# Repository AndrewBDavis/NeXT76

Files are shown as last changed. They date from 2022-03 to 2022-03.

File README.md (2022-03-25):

NeXT76 Left-Handed Alps Keyboard
=====================
The primary goal of this project was create as PCB and accompanying layered acrylic case to exclusively support NeXT non-adb keycaps and Alps Electric SKCM/SKCL switches.

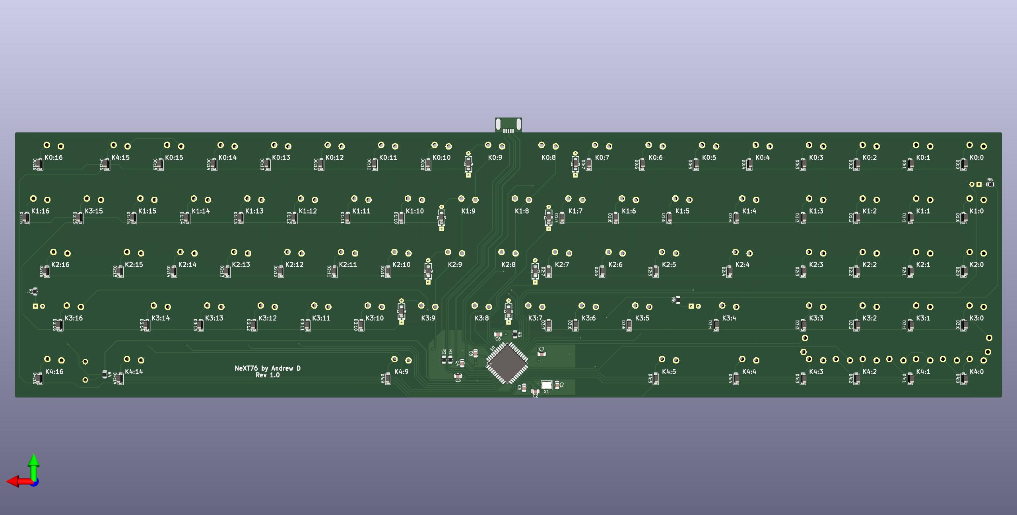
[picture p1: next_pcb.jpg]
next_pcb

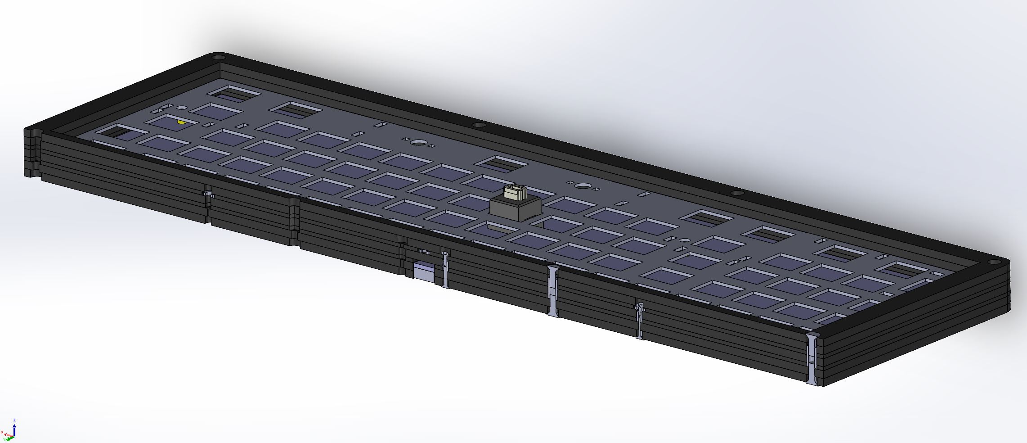
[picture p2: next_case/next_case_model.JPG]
next_model


Supported Layouts
---------------
This keyboard only supports a [modifed NeXT non-adb layout](https://tinyurl.com/mrxz3pk3) with no volume, brightness or arrow keys and a numpad that is moved to the left of the alphanumericals. Shift key leds are supported.

Numpad Layouts supported:  
| 1u | 1u | 1u | 1u |  | 1u | 1u | 1u | 1u |  | 1u | 1u | 1u | 1u |
|----|----|----|----|--|----|----|----|----|--|----|----|----|----|
| 1u | 1u | 1u | 1u |  | 1u | 1u | 1u | 1u |  | 1u | 1u | 1u | 1u |
| 1u | 1u | 1u | 1u |  | 1u | 1u | 1u | 1u |  | 1u | 1u | 1u | 1u |
| 1u | 1u | 1u | 2u |  | 2u | 1u | 1u | 1u |  | 1u | 1u | 1u | 1u |
| 2u | 2u | 1u | 2u |  | 2u | 1u | 2u | 2u |  | 1u | 2u | 2u | 1u |  

(Some layouts not shown explicitly)

BOM for Alps76 keyboard                                                  
------------------
| REF:  | VALUE: | FOOTPRINT: | COMPONENT |
|--- | --- | --- | --- |
| C1 | 22p | C_0805 | |
| C2 | 22p | C_0805 | | 
| C3 | 1u | C_0805 | |
| C4 | 4.7u | C_0805 | |
| C5 | 0.1u | C_0805 | |
| C6 | 0.1u | C_0805 | |
| C7 | 0.1u | C_0805 | |
| C8 | 0.1u | C_0805 | |
| J1 | USB_mini_B | USB_miniB_hirose_5S8 | UX60SC-MB-5S8 Hirose |
| R1 | 22 | R_0805 | |
| R2 | 22 | R_0805 | |
| R3 | 10K | R_0805 | |
| R4 | 10K | R_0805 | |
| R5 | 1K | R_0805 | |
| R6 | 1K | R_0805 | |
| R7 | 1K | R_0805 | |
| SW1 | SW_PUSH | Custom | TE 1825966-1 |
| U1 | ATMEGA32U4 | QFP44 | ATMega32u4-AU | 
| X1 | CRYSTAL | FA-238 | 16MHz, 12PF |
| D(78) | DIODE | SOD-123 | 1N4148 |
| LED(3)| LED | LED_D3.0mm | 3mm Round Top LED |

Revisions
-------------
V0.0: 	Prototype  
V1.0: 	Initial Release  
&emsp;&emsp;&nbsp;&nbsp;Cleaned up trace routing  
&emsp;&emsp;&nbsp;&nbsp;Added more numpad configurations  
V1.1: 	Added second numpad LED location option  
V1.2: 	Updated diode footprints,

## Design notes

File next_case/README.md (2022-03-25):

NeXT76 Acrylic Keyboard Case 
=====================
Layered acrylic layered case consisting of:
---------------
2 layers of 3mm acrylic  (Matte Top Layer Reccomended)  
1 layer of 1.5mm acrylic (1.2mm FR4 plate sits in-line with this layer)   
1 layer of 3mm acrylic (1.2mm FR4 plate sits on top of this layer)  
1 layer of 1.5mm acrylic 
2 layers of 3mm acrylic (Matte Bottom Layer Reccomended)  

Requried Hardware:
---------------
| Description | Thread | Length | Qty: | Locations: | Part number or Standard : |
|---|---|---|---|---|---|
| Hex Standoff Spacers | M3 | 8mm | 8 | Main Mouting Points | M1255-3005-AL |
| Round Standoff Spacers (Brass) | M2 | 4mm | 7 | USB, Plate Mounting | Generic, D3mm |
| Countersunk Hex Socket Screws  | M3 | 8mm | 16 | Main Mouting Points | ISO 10642 / DIN 7991 |
| Countersunk Hex Socket Screws  | M2 | 8mm | 7 | USB, Plate Mounting Points (Bottom) | ISO 10642 / DIN 7991 |
| Button Head Hex Socket Screws  | M2 | 4mm | 7 | USB, Plate Mounting Points (Top) | ISO 7380 / DIN 9427 |

Optional Hardware:
---------------
| Description | Qty: | Notes: |
|---|---|---|
| 22mm Anodized Aluminum Cone Feet | 3 is recommended | Available from Drop, KBDFans, Aliexpress etc. |

**Please note:** To use the aluminum feet, you must use the inclueded countersunk M4 screws and clip the legs of the switches mounted directly above screws and ensure the two are not making contact.

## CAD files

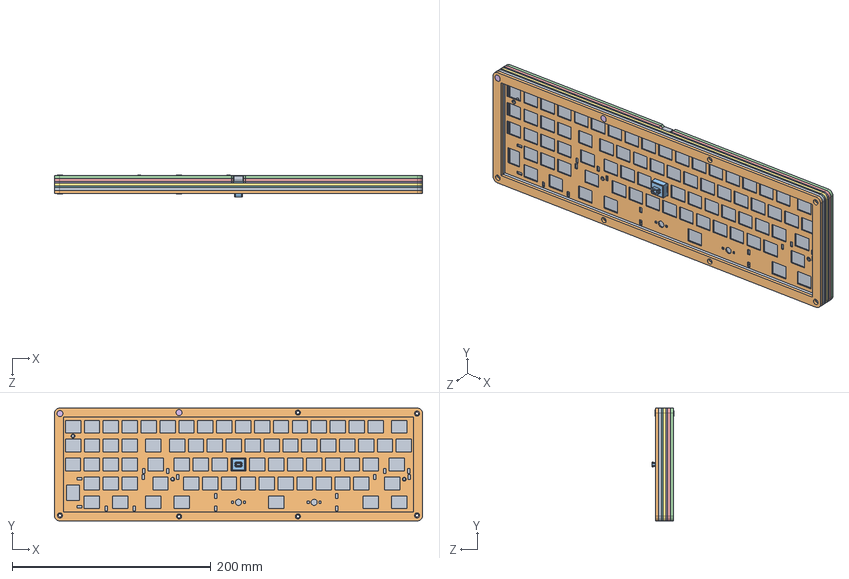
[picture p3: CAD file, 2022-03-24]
next_case/next_case_model/next_assembly.SLDASM
370.8 x 113.6 x 21.9 mm
pcb_next
plate
alps_switch
3mm_matte_1
3mm_2
1_5mm_3
3mm_4
1_5mm_5
3mm_6
3mm_matte_7
hex_spacer x 2
m2_countersunk x 2
m2_button x 2
m3_countersunk x 4

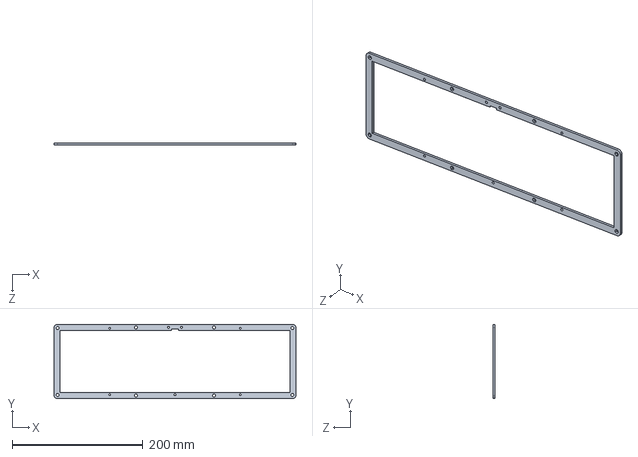
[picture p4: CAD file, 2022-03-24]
next_case/next_case_model/3mm_4.SLDPRT
370.8 x 113.6 x 3.00 mm

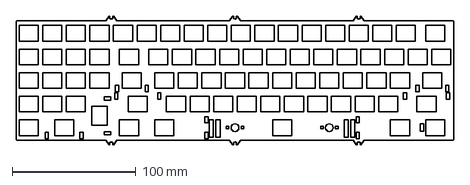
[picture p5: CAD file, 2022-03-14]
next_plate/next_plate.dxf
353.8 x 104.2 mm

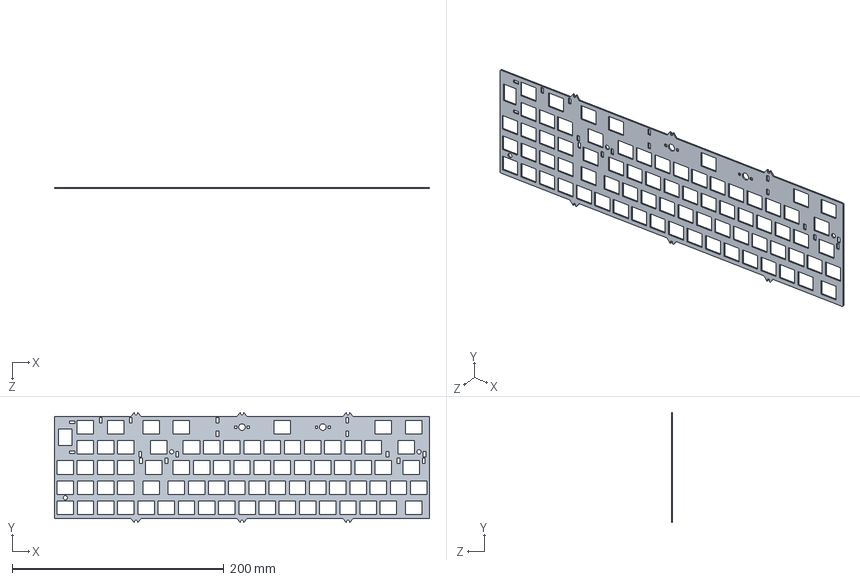
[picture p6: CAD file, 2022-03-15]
next_case/next_case_model/plate.SLDPRT
353.8 x 104.1 x 1.20 mm

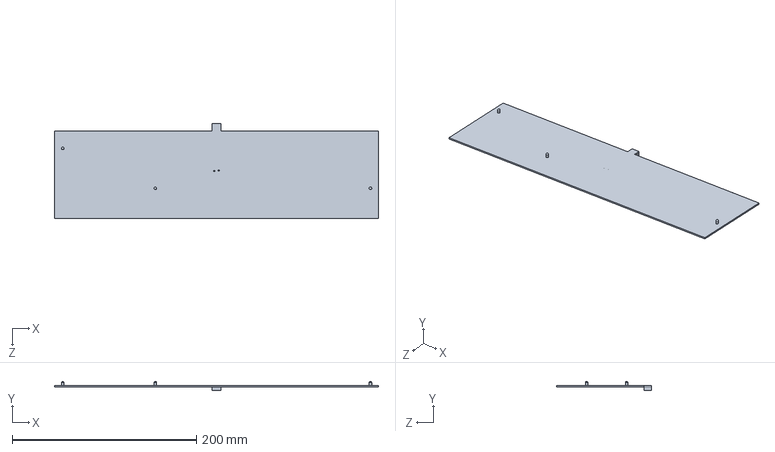
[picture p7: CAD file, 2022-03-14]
next_case/next_case_model/pcb_next.SLDPRT
351.4 x 10.1 x 103.2 mm

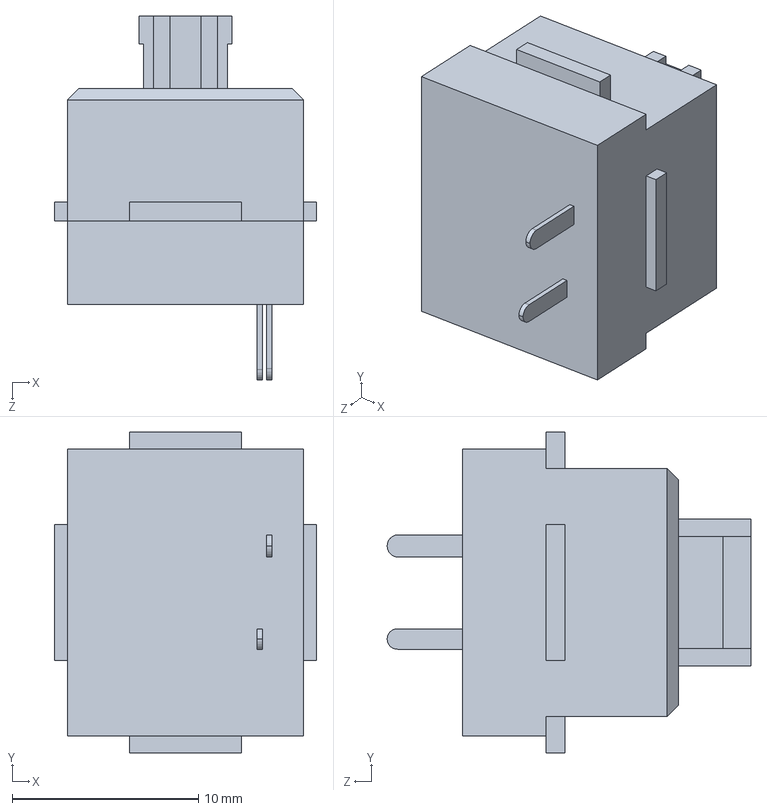
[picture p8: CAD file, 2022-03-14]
next_case/next_case_model/alps_switch.SLDPRT
14.1 x 17.2 x 19.6 mm

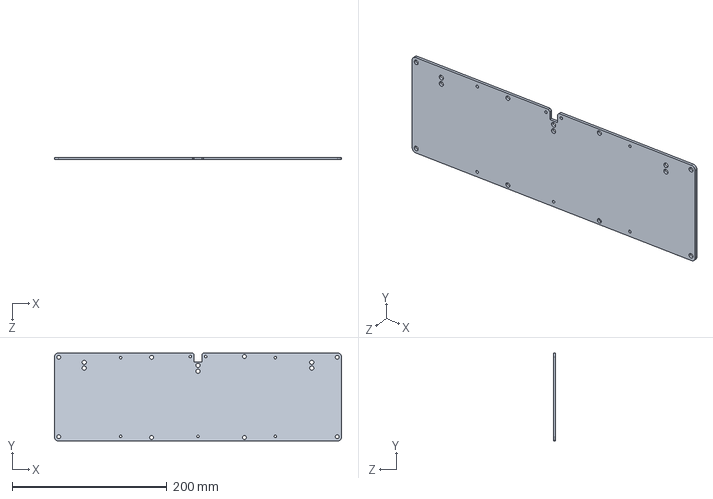
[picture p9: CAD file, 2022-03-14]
next_case/next_case_model/3mm_matte_1.SLDPRT
370.8 x 113.6 x 3.00 mm

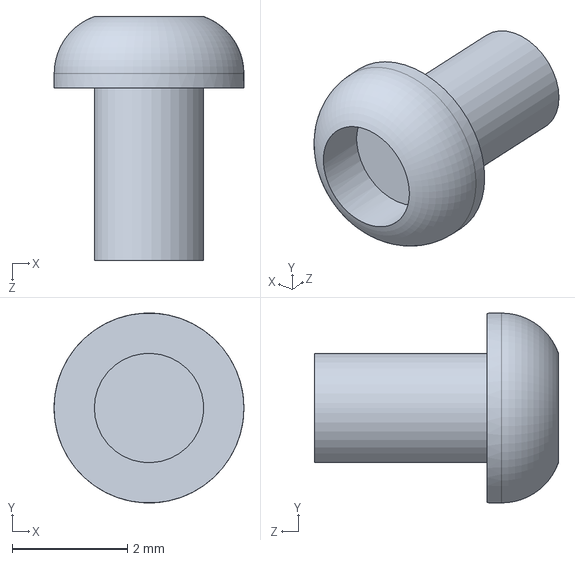
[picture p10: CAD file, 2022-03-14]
next_case/next_case_model/m2_button.SLDPRT
3.30 x 3.30 x 4.24 mm

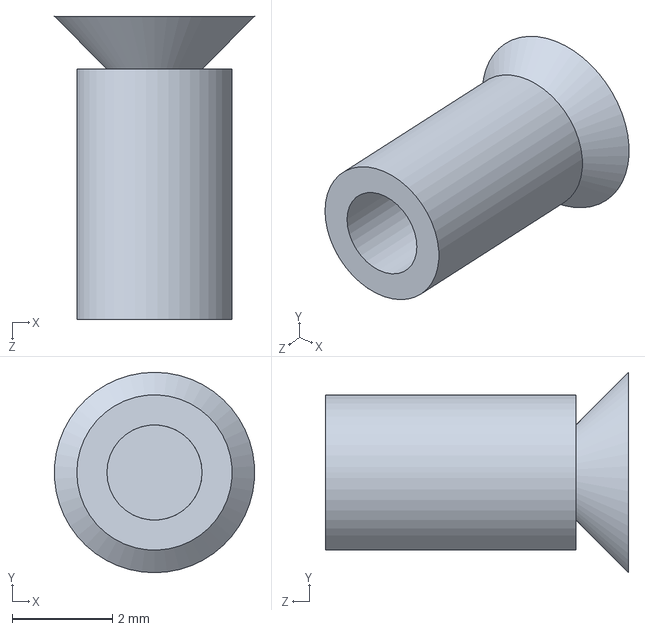
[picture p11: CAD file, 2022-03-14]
next_case/next_case_model/m2_countersunk.SLDPRT
3.99 x 4.00 x 6.05 mm

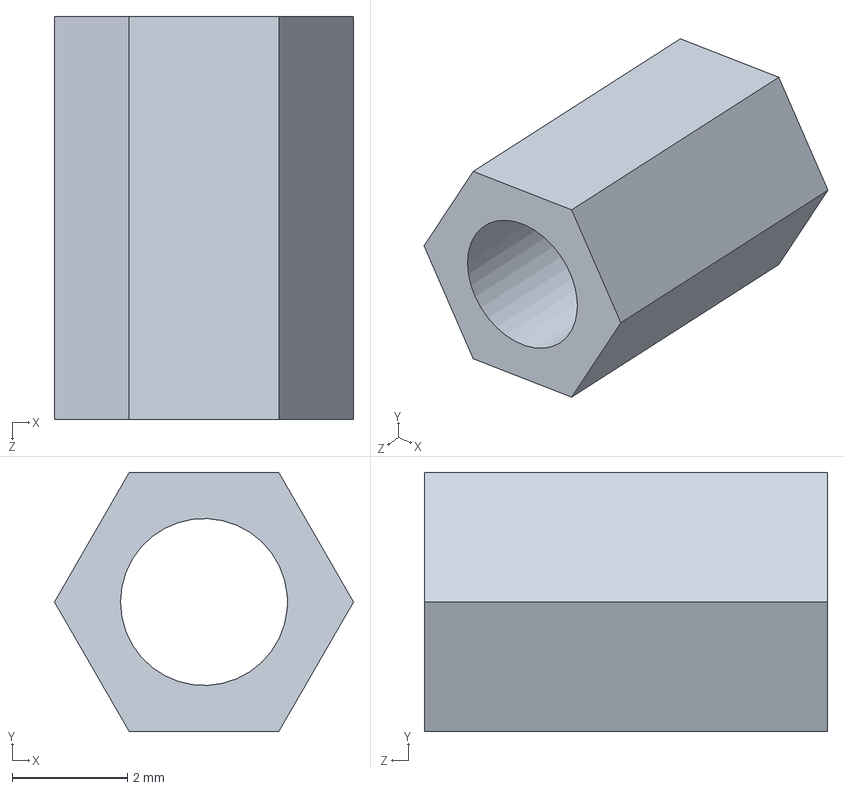
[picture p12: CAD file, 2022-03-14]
next_case/next_case_model/hex_spacer.SLDPRT
5.20 x 4.50 x 7.00 mm

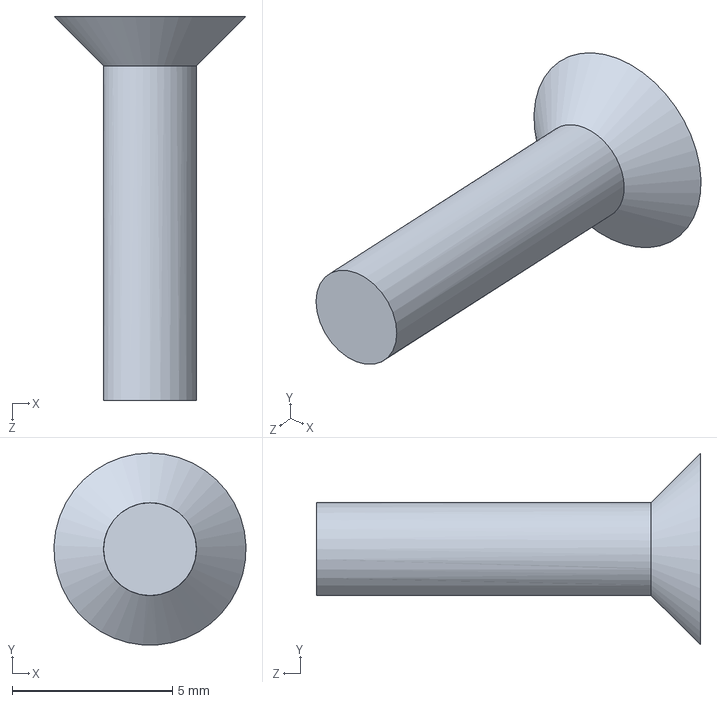
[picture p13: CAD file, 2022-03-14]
next_case/next_case_model/m3_countersunk.SLDPRT
6.00 x 5.99 x 12.0 mm

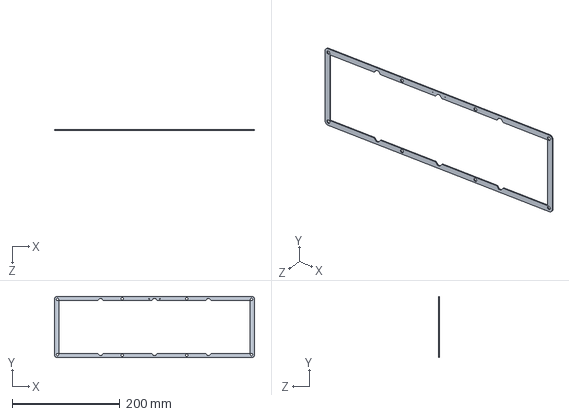
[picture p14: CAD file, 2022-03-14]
next_case/next_case_model/1_5mm_5.SLDPRT
370.8 x 113.6 x 1.50 mm

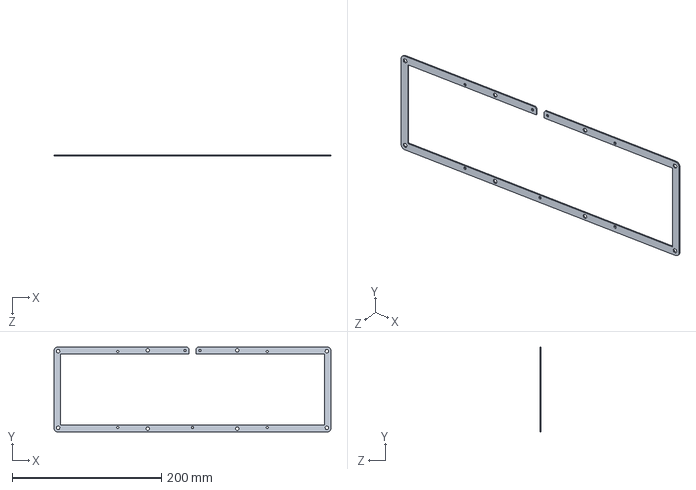
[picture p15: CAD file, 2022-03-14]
next_case/next_case_model/1_5mm_3.SLDPRT
370.8 x 113.6 x 1.50 mm

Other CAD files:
next_case/black_3_mm.dwg
next_case/matte_black_3_mm.dwg
next_case/black_1_5_mm.dwg
next_case/next_case_model/3mm_matte_7.SLDPRT
next_case/next_case_model/3mm_2.SLDPRT
next_case/next_case_model/3mm_6.SLDPRT
next_case/next_case_model/m2_washer.SLDPRT

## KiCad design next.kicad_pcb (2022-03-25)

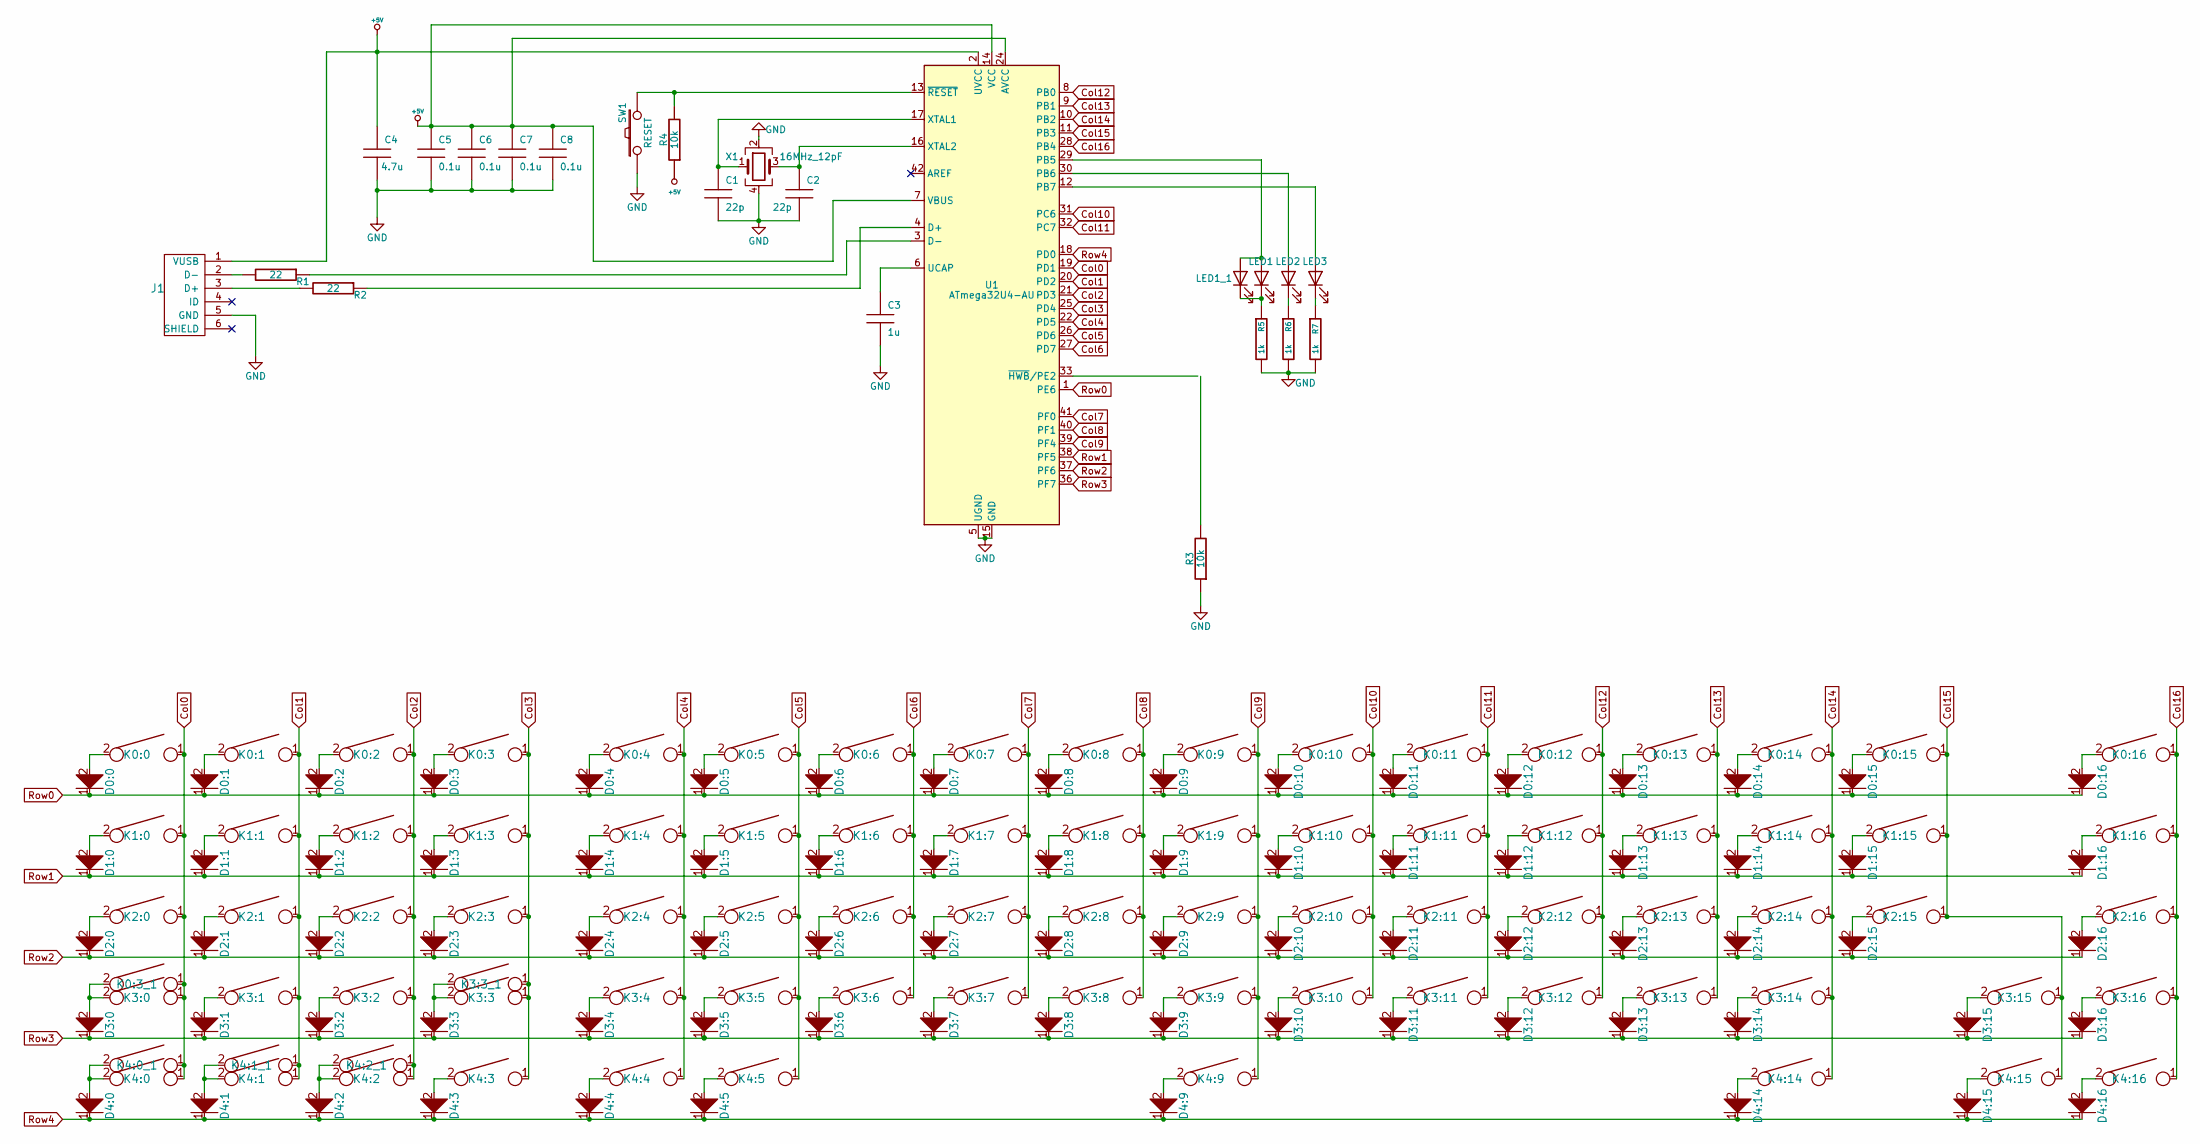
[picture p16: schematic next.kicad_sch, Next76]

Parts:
C1, C2: 22p; C_0805_2012Metric
C3: 1u; C_0805_2012Metric
C4: 4.7u; C_0805_2012Metric
C5, C6, C7, C8: 0.1u; C_0805_2012Metric
D0:0, D0:1, D0:2, D0:3, D0:4, D0:5, D0:6, D0:7, D0:8, D0:9, D0:10, D0:11, D0:12, D0:13, D0:14, D0:15, D0:16, D1:0, D1:1, D1:2, D1:3, D1:4, D1:5, D1:6, D1:7, D1:8, D1:9, D1:10, D1:11, D1:12, D1:13, D1:14, D1:15, D1:16, D2:0, D2:1, D2:2, D2:3, D2:4, D2:5, D2:6, D2:7, D2:8, D2:9, D2:10, D2:11, D2:12, D2:13, D2:14, D2:15, D2:16, D3:0, D3:1, D3:2, D3:3, D3:4, D3:5, D3:6, D3:7, D3:8, D3:9, D3:10, D3:11, D3:12, D3:13, D3:14, D3:15, D3:16, D4:0, D4:1, D4:2, D4:3, D4:4, D4:5, D4:9, D4:14, D4:15, D4:16: D; D_SOD-123
J1: USB_mini_micro_B; USB_miniB_hirose_5S8
K0:0, K0:1, K0:2, K0:3, K0:4, K0:5, K0:6, K0:7, K0:8, K0:9, K0:10, K0:11, K0:12, K0:13, K0:14, K0:15, K0:16, K1:0, K1:1, K1:2, K1:3, K1:4, K1:5, K1:6, K1:7, K1:8, K1:9, K1:10, K1:11, K1:12, K1:13, K1:14, K1:15, K1:16, K2:0, K2:1, K2:2, K2:3, K2:4, K2:5, K2:6, K2:7, K2:8, K2:9, K2:10, K2:11, K2:12, K2:13, K2:14, K2:15, K2:16, K3:0, K3:1, K3:2, K3:3, K3:4, K3:5, K3:6, K3:7, K3:8, K3:9, K3:10, K3:11, K3:12, K3:13, K3:14, K3:15, K3:16, K4:0, K4:1, K4:2, K4:3, K4:4, K4:5, K4:9, K4:14, K4:15, K4:16: KEYSW; Alps
K0:3_1, K3:3_1, K4:0_1, K4:1_1, K4:2_1: KEYSW; Alps_Secondary
LED1, LED1_1, LED2, LED3: LED; LED_D3.0mm
R1, R2: 22; R_0805_2012Metric
R3, R4: 10k; R_0805_2012Metric
R5, R6, R7: 1k; R_0805_2012Metric
SW1: RESET; TE_1825966-1
U1: ATmega32U4-AU; LQFP-44_10x10mm_P0.8mm
X1: 16MHz_12pF; Crystal_SMD_SeikoEpson_FA238-4Pin_3.2x2.5mm

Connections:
+5V: C4.1, C5.1, C6.1, C7.1, C8.1, J1.1 (VUSB), R4.1, U1.2 (UVCC), U1.7 (VBUS), U1.14 (VCC), U1.24 (AVCC), U1.34 (VCC), U1.44 (AVCC)
Col0: K0:0.1, K0:3_1.1, K1:0.1, K2:0.1, K3:0.1, K4:0.1, K4:0_1.1, U1.19 (PD1)
Col1: K0:1.1, K1:1.1, K2:1.1, K3:1.1, K4:1.1, K4:1_1.1, U1.20 (PD2)
Col2: K0:2.1, K1:2.1, K2:2.1, K3:2.1, K4:2.1, K4:2_1.1, U1.21 (PD3)
Col3: K0:3.1, K1:3.1, K2:3.1, K3:3.1, K3:3_1.1, K4:3.1, U1.25 (PD4)
Col4: K0:4.1, K1:4.1, K2:4.1, K3:4.1, K4:4.1, U1.22 (PD5)
Col5: K0:5.1, K1:5.1, K2:5.1, K3:5.1, K4:5.1, U1.26 (PD6)
Col6: K0:6.1, K1:6.1, K2:6.1, K3:6.1, U1.27 (PD7)
Col7: K0:7.1, K1:7.1, K2:7.1, K3:7.1, U1.41 (PF0)
Col8: K0:8.1, K1:8.1, K2:8.1, K3:8.1, U1.40 (PF1)
Col9: K0:9.1, K1:9.1, K2:9.1, K3:9.1, K4:9.1, U1.39 (PF4)
Col10: K0:10.1, K1:10.1, K2:10.1, K3:10.1, U1.31 (PC6)
Col11: K0:11.1, K1:11.1, K2:11.1, K3:11.1, U1.32 (PC7)
Col12: K0:12.1, K1:12.1, K2:12.1, K3:12.1, U1.8 (PB0)
Col13: K0:13.1, K1:13.1, K2:13.1, K3:13.1, U1.9 (PB1)
Col14: K0:14.1, K1:14.1, K2:14.1, K3:14.1, K4:14.1, U1.10 (PB2)
Col15: K0:15.1, K1:15.1, K2:15.1, K3:15.1, K4:15.1, U1.11 (PB3)
Col16: K0:16.1, K1:16.1, K2:16.1, K3:16.1, K4:16.1, U1.28 (PB4)
GND: C1.2, C2.2, C3.2, C4.2, C5.2, C6.2, C7.2, C8.2, J1.5 (GND), R3.1, R5.2, R6.2, R7.2, SW1.1, U1.5 (UGND), U1.15 (GND), U1.23 (GND), U1.35 (GND), U1.43 (GND), X1.2, X1.4
unnamed: C1.1, U1.17 (XTAL1), X1.1
unnamed: C2.1, U1.16 (XTAL2), X1.3
unnamed: C3.1, U1.6 (UCAP)
unnamed: D0:0.2, K0:0.2
unnamed: D0:1.2, K0:1.2
unnamed: D0:2.2, K0:2.2
unnamed: D0:3.2, K0:3.2
unnamed: D0:4.2, K0:4.2
unnamed: D0:5.2, K0:5.2
unnamed: D0:6.2, K0:6.2
unnamed: D0:7.2, K0:7.2
unnamed: D0:8.2, K0:8.2
unnamed: D0:9.2, K0:9.2
unnamed: D0:10.2, K0:10.2
unnamed: D0:11.2, K0:11.2
unnamed: D0:12.2, K0:12.2
unnamed: D0:13.2, K0:13.2
unnamed: D0:14.2, K0:14.2
unnamed: D0:15.2, K0:15.2
unnamed: D0:16.2, K0:16.2
unnamed: D1:0.2, K1:0.2
unnamed: D1:1.2, K1:1.2
unnamed: D1:2.2, K1:2.2
unnamed: D1:3.2, K1:3.2
unnamed: D1:4.2, K1:4.2
unnamed: D1:5.2, K1:5.2
unnamed: D1:6.2, K1:6.2
unnamed: D1:7.2, K1:7.2
unnamed: D1:8.2, K1:8.2
unnamed: D1:9.2, K1:9.2
unnamed: D1:10.2, K1:10.2
unnamed: D1:11.2, K1:11.2
unnamed: D1:12.2, K1:12.2
unnamed: D1:13.2, K1:13.2
unnamed: D1:14.2, K1:14.2
unnamed: D1:15.2, K1:15.2
unnamed: D1:16.2, K1:16.2
unnamed: D2:0.2, K2:0.2
unnamed: D2:1.2, K2:1.2
unnamed: D2:2.2, K2:2.2
unnamed: D2:3.2, K2:3.2
unnamed: D2:4.2, K2:4.2
unnamed: D2:5.2, K2:5.2
unnamed: D2:6.2, K2:6.2
unnamed: D2:7.2, K2:7.2
unnamed: D2:8.2, K2:8.2
unnamed: D2:9.2, K2:9.2
unnamed: D2:10.2, K2:10.2
unnamed: D2:11.2, K2:11.2
unnamed: D2:12.2, K2:12.2
unnamed: D2:13.2, K2:13.2
unnamed: D2:14.2, K2:14.2
unnamed: D2:15.2, K2:15.2
unnamed: D2:16.2, K2:16.2
unnamed: D3:0.2, K0:3_1.2, K3:0.2
unnamed: D3:1.2, K3:1.2
unnamed: D3:2.2, K3:2.2
unnamed: D3:3.2, K3:3.2, K3:3_1.2
unnamed: D3:4.2, K3:4.2
unnamed: D3:5.2, K3:5.2
unnamed: D3:6.2, K3:6.2
unnamed: D3:7.2, K3:7.2
unnamed: D3:8.2, K3:8.2
unnamed: D3:9.2, K3:9.2
unnamed: D3:10.2, K3:10.2
unnamed: D3:11.2, K3:11.2
unnamed: D3:12.2, K3:12.2
unnamed: D3:13.2, K3:13.2
unnamed: D3:14.2, K3:14.2
unnamed: D3:15.2, K3:15.2
unnamed: D3:16.2, K3:16.2
unnamed: D4:0.2, K4:0.2, K4:0_1.2
unnamed: D4:1.2, K4:1.2, K4:1_1.2
unnamed: D4:2.2, K4:2.2, K4:2_1.2
unnamed: D4:3.2, K4:3.2
unnamed: D4:4.2, K4:4.2
unnamed: D4:5.2, K4:5.2
unnamed: D4:9.2, K4:9.2
unnamed: D4:14.2, K4:14.2
unnamed: D4:15.2, K4:15.2
unnamed: D4:16.2, K4:16.2
unnamed: J1.2 (D-), R1.2
unnamed: J1.3 (D+), R2.2
unnamed: LED1.1 (K), LED1_1.1 (K), R5.1
unnamed: LED1.2 (A), LED1_1.2 (A), U1.29 (PB5)
unnamed: LED2.1 (K), R6.1
unnamed: LED2.2 (A), U1.30 (PB6)
unnamed: LED3.1 (K), R7.1
unnamed: LED3.2 (A), U1.12 (PB7)
unnamed: R1.1, U1.3 (D-)
unnamed: R2.1, U1.4 (D+)
unnamed: R3.2, U1.33 (~HWB/PE2)
unnamed: R4.2, SW1.2, U1.13 (~RESET)
Row0: D0:0.1, D0:1.1, D0:2.1, D0:3.1, D0:4.1, D0:5.1, D0:6.1, D0:7.1, D0:8.1, D0:9.1, D0:10.1, D0:11.1, D0:12.1, D0:13.1, D0:14.1, D0:15.1, D0:16.1, U1.1 (PE6)
Row1: D1:0.1, D1:1.1, D1:2.1, D1:3.1, D1:4.1, D1:5.1, D1:6.1, D1:7.1, D1:8.1, D1:9.1, D1:10.1, D1:11.1, D1:12.1, D1:13.1, D1:14.1, D1:15.1, D1:16.1, U1.38 (PF5)
Row2: D2:0.1, D2:1.1, D2:2.1, D2:3.1, D2:4.1, D2:5.1, D2:6.1, D2:7.1, D2:8.1, D2:9.1, D2:10.1, D2:11.1, D2:12.1, D2:13.1, D2:14.1, D2:15.1, D2:16.1, U1.37 (PF6)
Row3: D3:0.1, D3:1.1, D3:2.1, D3:3.1, D3:4.1, D3:5.1, D3:6.1, D3:7.1, D3:8.1, D3:9.1, D3:10.1, D3:11.1, D3:12.1, D3:13.1, D3:14.1, D3:15.1, D3:16.1, U1.36 (PF7)
Row4: D4:0.1, D4:1.1, D4:2.1, D4:3.1, D4:4.1, D4:5.1, D4:9.1, D4:14.1, D4:15.1, D4:16.1, U1.18 (PD0)

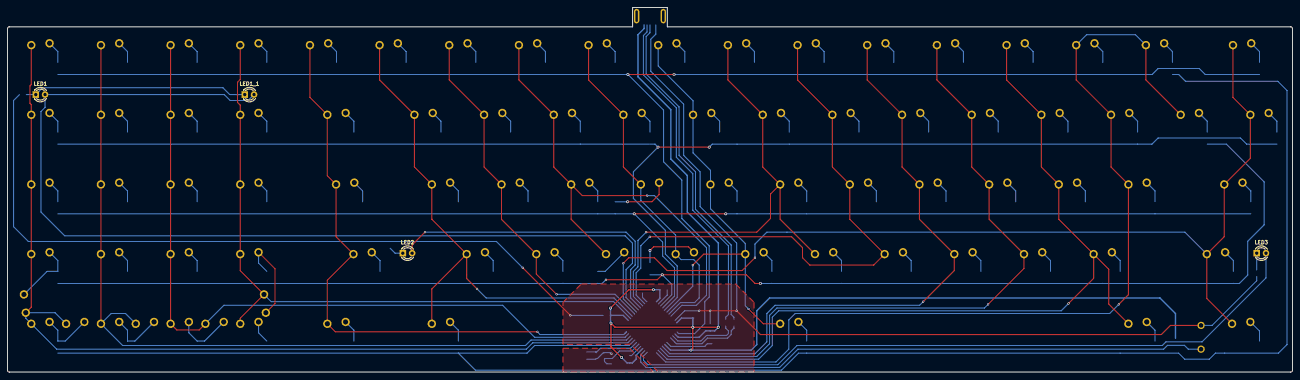
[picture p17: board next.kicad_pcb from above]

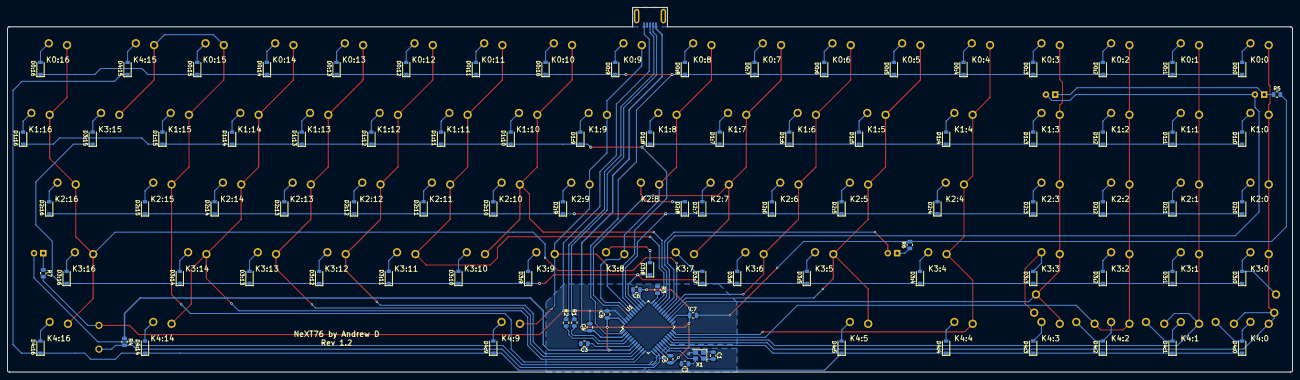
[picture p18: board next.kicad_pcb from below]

Board: 2 copper layers, 351.4 x 99.7 mm, 184 parts (97 on the bottom side), 117 nets.

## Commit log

2022-03-14 Updated Model
    [Switch.SLDPRT, alps_switch.SLDPRT, black_1_5_mm.dwg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]
2022-03-14 Update Model
    [1_5mm_3.SLDPRT, 1_5mm_5.SLDPRT, 3mm_2.SLDPRT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]
2022-03-15 Numpad Config Changed
    [1_5mm_3.SLDPRT, 1_5mm_5.SLDPRT, 3mm_2.SLDPRT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]
2022-03-15 Update Picture
    [next_assembly.SLDASM]
2022-03-18 Update Axial_Diode Footprint
    [next.kicad_pcb, next.kicad_sch]
2022-03-23 Added LED opttion
    [next.kicad_pcb, next.kicad_sch, next_plate.kicad_pcb]
2022-03-23 Update diodes
    [next.kicad_pcb, next.kicad_sch]
2022-03-24 Extend USB port mount
    [3mm_4.SLDPRT, black_3_mm.dwg, matte_black_3_mm.dwg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]
2022-03-25 Adjust USB port
    [black_3_mm.dwg, next.kicad_pcb]
